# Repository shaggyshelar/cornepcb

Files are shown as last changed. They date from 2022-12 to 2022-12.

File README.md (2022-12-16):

# samoklava

## An autogenerated split 36 key keyboard

## Disclaimer

This is an early experimental prototype. Please do not rely on the autogenerated files and double check them manually
before sending them off to a PCB fab. The author and other random strangers on the internet have been able to produce
working keyboard prototypes from this repo; this does not mean that everything will work every time.

The author(s) waive(s) responsibility for any damage or regulatory violations caused by using this software (see
license). Please consult your local regulations around radio frequencies and what's allowed for DIY projects in your
country.

| left | right |
| --- | --- |
| left | right |

A 5x3 split keyboard with 3 thumb keys. There is nothing unique about the keyboard layout. It's inspired by Corne and
Kyria, and has the exact number of keys needed for the [Miryoku](https://github.com/manna-harbour/miryoku) layout.

The interesting thing about this keyboard is that it's a declarative design:

- Layout is declared using [Ergogen](https://github.com/mrzealot/ergogen/). See [this fork](https://github.com/soundmonster/ergogen).
- The build system uses Ergogen to translate YAML to a KiCad PCB and plate files for FR-4 fab or laser cutting
- uses [kicad-automation-scripts](https://github.com/productize/kicad-automation-scripts) and [FreeRouting](https://github.com/freerouting/freerouting) to **automatically route the traces on the PCB**
- uses [KiKit](https://github.com/yaqwsx/KiKit) to render PCB previews (see top of this file) and production-ready **Gerber files**

## Features

- Extra pins and a slider switch for battery for wireless Promicro clones (tested with nice!nano); the slider can be
  shorted with a jumper if `CONFIG_ZMK_SLEEP` is preferred.
- Wired operation with QMK should be possible but is not tested; TRRS footprints are included and routed. The pinout is
  identical with a five-column Corne sans the RGBLEDs.
- Reset switches are easily accessible. The footprints used are the same as on the Corne.

## How to

If you would like to modify this:

- fork it
- change `samoklava.yaml` to your liking
- push your changes; the `build.yml` GitHub Workflow will pick it up, autoroute and generate Gerbers, all in a zip file.
  See https://github.com/soundmonster/samoklava/actions
- or:
  - make sure to have Docker CLI and NodeJS installed
  - run `make setup clean all`
  - check the `output` folder for KiCad PCBs and Gerbers

See the [workflow](.github/workflows/build.yml) or the [Makefile](Makefile) for more details.
See [my ZMK config](https://github.com/soundmonster/samoklava-zmk-config) for a suggested keymap.

# Initialize

`make run init-footprint`

## Update following file and add below code

/node_modules/ergogen/src/footprints/index.js

`   bat: require('./bat'),
    b3u1000p: require('./b3u1000p'),
    pcm12: require('./pcm12'),
    promicro_pretty: require('./promicro_pretty')`

## Once files are generated then run following plugins

- freerouting
- Teardrops
- Round Tracks

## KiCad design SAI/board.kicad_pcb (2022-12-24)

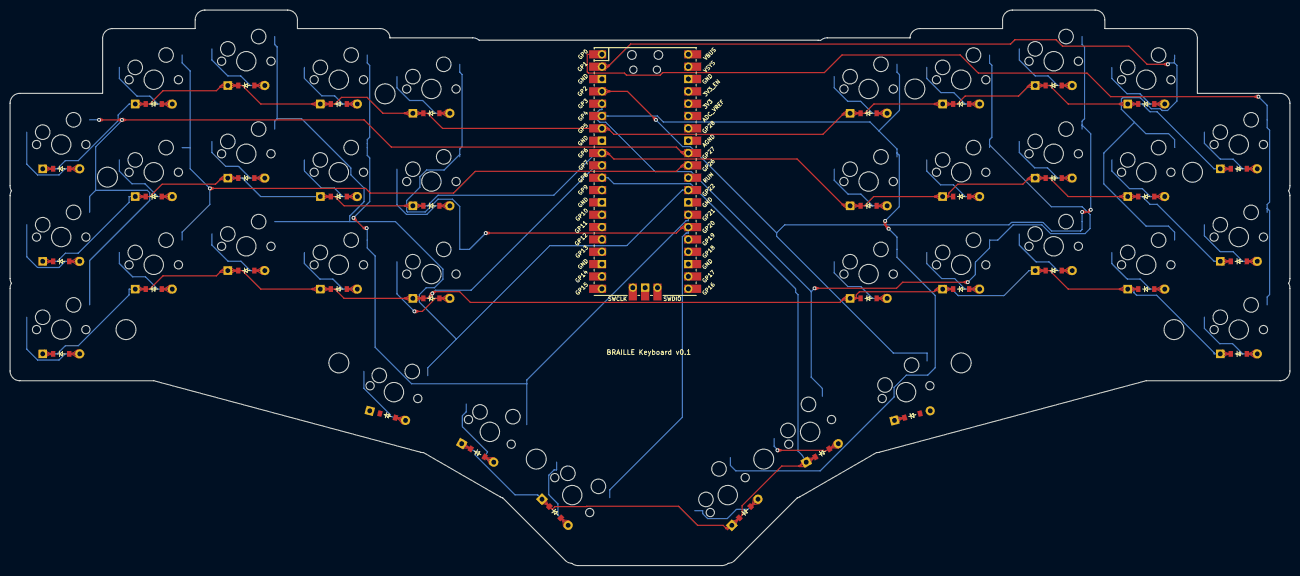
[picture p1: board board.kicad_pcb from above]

Board: 2 copper layers, 263.5 x 114.3 mm, 73 parts (0 on the bottom side), 50 nets.

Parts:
D1, D2, D3, D4, D5, D6, D7, D8, D9, D10, D11, D12, D13, D14, D15, D16, D17, D18, D19, D20, D21, D22, D23, D24, D25, D26, D27, D28, D29, D30, D31, D32, D33, D34, D35, D36: ComboDiode
MCU1: RPi_Pico_SMD_TH
S1, S2, S3, S4, S5, S6, S7, S8, S9, S10, S11, S12, S13, S14, S15, S16, S17, S18, S19, S20, S21, S22, S23, S24, S25, S26, S27, S28, S29, S30, S31, S32, S33, S34, S35, S36: MX

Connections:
C1: MCU1.32, S1.2, S2.2, S3.2
C2: MCU1.31, S4.2, S5.2, S6.2
C3: MCU1.29, S7.2, S8.2, S9.2, S16.2
C4: MCU1.27, S10.2, S11.2, S12.2, S17.2
C5: MCU1.26, S13.2, S14.2, S15.2, S18.2
C6: MCU1.6, S31.2, S32.2, S33.2, S36.2
C7: MCU1.5, S28.2, S29.2, S30.2, S35.2
C8: MCU1.4, S25.2, S26.2, S27.2, S34.2
C9: MCU1.2, S22.2, S23.2, S24.2
C10: MCU1.1, S19.2, S20.2, S21.2
R1: D3.1, D3.2, D6.1, D6.2, D9.1, D9.2, D12.1, D12.2, D15.1, D15.2, D21.1, D21.2, D24.1, D24.2, D27.1, D27.2, D30.1, D30.2, D33.1, D33.2, MCU1.7
R2: D2.1, D2.2, D5.1, D5.2, D8.1, D8.2, D11.1, D11.2, D14.1, D14.2, D20.1, D20.2, D23.1, D23.2, D26.1, D26.2, D29.1, D29.2, D32.1, D32.2, MCU1.9
R3: D1.1, D1.2, D4.1, D4.2, D7.1, D7.2, D10.1, D10.2, D13.1, D13.2, D19.1, D19.2, D22.1, D22.2, D25.1, D25.2, D28.1, D28.2, D31.1, D31.2, MCU1.10
R4: D16.1, D16.2, D17.1, D17.2, D18.1, D18.2, D34.1, D34.2, D35.1, D35.2, D36.1, D36.2, MCU1.11
far_thumb: D18.1, D18.2, S18.1
home_thumb: D17.1, D17.2, S17.1
index_bottom: D10.1, D10.2, S10.1
index_home: D11.1, D11.2, S11.1
index_top: D12.1, D12.2, S12.1
inner_bottom: D13.1, D13.2, S13.1
inner_home: D14.1, D14.2, S14.1
inner_top: D15.1, D15.2, S15.1
middle_bottom: D7.1, D7.2, S7.1
middle_home: D8.1, D8.2, S8.1
middle_top: D9.1, D9.2, S9.1
mirror_far_thumb: D36.1, D36.2, S36.1
mirror_home_thumb: D35.1, D35.2, S35.1
mirror_index_bottom: D28.1, D28.2, S28.1
mirror_index_home: D29.1, D29.2, S29.1
mirror_index_top: D30.1, D30.2, S30.1
mirror_inner_bottom: D31.1, D31.2, S31.1
mirror_inner_home: D32.1, D32.2, S32.1
mirror_inner_top: D33.1, D33.2, S33.1
mirror_middle_bottom: D25.1, D25.2, S25.1
mirror_middle_home: D26.1, D26.2, S26.1
mirror_middle_top: D27.1, D27.2, S27.1
mirror_near_thumb: D34.1, D34.2, S34.1
mirror_pinky_bottom: D19.1, D19.2, S19.1
mirror_pinky_home: D20.1, D20.2, S20.1
mirror_pinky_top: D21.1, D21.2, S21.1
mirror_ring_bottom: D22.1, D22.2, S22.1
mirror_ring_home: D23.1, D23.2, S23.1
mirror_ring_top: D24.1, D24.2, S24.1
near_thumb: D16.1, D16.2, S16.1
pinky_bottom: D1.1, D1.2, S1.1
pinky_home: D2.1, D2.2, S2.1
pinky_top: D3.1, D3.2, S3.1
ring_bottom: D4.1, D4.2, S4.1
ring_home: D5.1, D5.2, S5.1
ring_top: D6.1, D6.2, S6.1

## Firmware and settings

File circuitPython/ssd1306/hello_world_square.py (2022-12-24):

import os
import time
import busio
import board
import displayio
import terminalio
import adafruit_displayio_ssd1306
from adafruit_display_text import label

WIDTH = 128
HEIGHT = 64
CENTER_X = int(WIDTH/2)
CENTER_Y = int(HEIGHT/2)
BORDER = 5

displayio.release_displays()

# Initialize and lock the I2C bus.
i2c = busio.I2C(board.IO40, board.IO42)
while not i2c.try_lock():
    pass

print("$$$$$$$$$$$ Starting scan")
# Find the first I2C device available.
devices = i2c.scan()
while len(devices) < 1:
    devices = i2c.scan()
device = devices[0]
print('Found device with address: {}'.format(hex(device)))

i2c.unlock()


print("Initializing Library ..")
# Output: Found device with address: 0x3c

display_bus = displayio.I2CDisplay(i2c, device_address=0x3c)
display = adafruit_displayio_ssd1306.SSD1306(display_bus, width=128, height=64)


splash = displayio.Group()
display.show(splash)

color_bitmap = displayio.Bitmap(WIDTH, HEIGHT, 1)
color_palette = displayio.Palette(1)
color_palette[0] = 0xFFFFFF  # White
bg_sprite = displayio.TileGrid(
    color_bitmap, pixel_shader=color_palette, x=0, y=0)
splash.append(bg_sprite)
# Draw a smaller inner rectangle
inner_bitmap = displayio.Bitmap(WIDTH - BORDER * 2, HEIGHT - BORDER * 2, 1)
inner_palette = displayio.Palette(1)
inner_palette[0] = 0x000000  # Black
inner_sprite = displayio.TileGrid(
    inner_bitmap, pixel_shader=inner_palette, x=BORDER, y=BORDER
)
splash.append(inner_sprite)
# Draw a label
text = "Hello World!"
text_area = label.Label(
    terminalio.FONT, text=text, color=0xFFFFFF, x=28, y=HEIGHT // 2 - 1
)
splash.append(text_area)
while True:
    pass

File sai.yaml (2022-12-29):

units:
  kx: U
  ky: U
  px: 2
  py: 2
points:
  key:
    footprints:
      mx_hotswap:
        type: mx
        params:
          hotswap: true
          reverse: false
          keycaps: true
        nets:
          from: =colrow
          to: =column_net
      # mx:
      #   type: mx
      #   params:
      #     reverse: false
      #     keycaps: true
      #   nets:
      #     from: =colrow
      #     to: =column_net
      diode:
        type: diode
        nets:
          from: =colrow
          to: =row_net
        anchor:
          shift: [0, -5]
  zones:
    matrix:
      # anchor:
      #   rotate: 5
      key.padding: ky
      columns:
        pinky:
          stagger: 0 ky
          spread: kx
          key:
            bind: [0,9,0,0]
            column_net: C1
            mirror.column_net: C10
        ring:
          stagger: 0.7 ky
          spread: kx
          key:
            column_net: C2
            mirror.column_net: C9
        middle:
          stagger: 0.2 ky
          spread: kx
          key:
            column_net: C3
            mirror.column_net: C8
        index:
          stagger: -0.2 ky
          spread: kx
          key:
            column_net: C4
            mirror.column_net: C7
        inner:
          stagger: -0.1 ky
          spread: kx
          key:
            # bind: [0,40,20,0]
            column_net: C5
            mirror.column_net: C6
      rows:
        bottom:
          row_net: R3
        home:
          row_net: R2
        top:
          row_net: R1
    thumbfan:
      anchor:
        ref: matrix_inner_bottom
        shift: [-1.5 kx, -1 ky]
      columns:
        near:
          spread: kx
          rotate: -15
          origin: [-1 kx, -0.5 ky]
          key:
            column_net: C3
            mirror.column_net: C8
        home:
          spread: kx
          rotate: -15
          origin: [-0.5 kx, -0.5 ky]
          key:
            column_net: C4
            mirror.column_net: C7
        far:
          spread: kx
          rotate: -15
          origin: [-0.5 kx, -0.5 ky]
          key:
            column_net: C5
            mirror.column_net: C6
      rows:
        thumb:
          row_net: R4
          bind: [20,0,0,55]
  # rotate: -1
  mirror:
    ref: matrix_inner_home
    distance: 90
outlines:
  # glue:
  #   default:
  #     top:
  #       left:
  #         ref: matrix_inner_top
  #         shift: [,sy / 2]
  #       right:
  #         ref: mirror_matrix_inner_top
  #         shift: [,sy / 2]
  #     bottom:
  #       left:
  #         ref: matrix_inner_bottom
  #         shift: [,sy / -2]
  #       right:
  #         ref: mirror_matrix_inner_bottom
  #         shift: [,sy / -2]
  exports:
    # optout:
    #   main:
    #     type: keys
    #     side: both
    #     size: 20
    #     glue: false
    #     corner: px
    raw:
      - type: keys
        side: both
        size: [kx + px, ky + py]
        corner: px
    # thumbfan_glue:
    #   - type: polygon
    #     points:
    #       - ref: matrix_inner_bottom
    #         shift: [0.5 kx + 0.5px, -0.5 ky + 0.5 py]
    #       - ref: thumbfan_far_thumb
    #         shift: [0.5 kx - 0.5px, 0.5 ky + 0.5 py]
    #       - ref: thumbfan_far_thumb
    #         shift: [0.5 kx - 0.5px, -0.5 ky - 0.5 py]
    #       - ref: thumbfan_near_thumb
    #         shift: [-0.5 kx + 0.5 px, -0.5 ky - 0.5 py]
    #       - ref: matrix_pinky_bottom
    #         shift: [0.5 kx - 0.5 py, -0.5 ky - 0.5 py]
    #       - ref: matrix_pinky_home
    #       - ref: matrix_inner_home
    # patch_outer:
    #   - type: polygon
    #     points:
    #       - ref: matrix_ring_top
    #       - ref: matrix_ring_bottom
    #       - ref: matrix_pinky_bottom
    #         shift: [-0.5 (kx + px), 0]
    #       - ref: matrix_pinky_top
    #         shift: [-0.5 (kx + px), 0]
    # patch_inner:
    #   - type: polygon
    #     points:
    #       - ref: matrix_inner_top
    #         shift: [0.5 (kx + px), 0]
    #       - ref: matrix_inner_bottom
    #         shift: [0.5 (kx + px), 0]
    #       - ref: matrix_index_bottom
    #       - ref: matrix_index_top
    # controller_area:
    #   main:
    #     type: rectangle
    #     anchor:
    #       ref:
    #         - matrix_inner_top
    #       shift: [0.5 kx, -4.34 ky]
    #     size: [34, 90]
    #     #   shift: [0 kx, -4.05 ky]
    #     # size: [32, 76.5]
    #     corner: px
    pico_area:
      main:
        type: rectangle
        anchor:
          ref:
            - matrix_inner_top
          shift: [0.4 kx, -3.2 ky]
        size: [74, 71]
        corner: px
    pcb_area:
      main:
        type: rectangle
        anchor:
          ref:
            - matrix_inner_top
          shift: [-87, -5.15 ky]
        size: [265, 6 ky]
        corner: px
    bottom_area:
      main:
        type: rectangle
        anchor:
          ref:
            - matrix_inner_top
          shift: [1.48 kx, -5.15 ky]
        size: [33.64, 30]
        corner: px
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

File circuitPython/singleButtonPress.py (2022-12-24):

"""
Top Left side of button is connected to IO4
Bottom Right side of button is connected to GND

Buttons Tested: IO4,IO5,IO6,IO7,IO15,IO16,IO17,IO18,IO8,IO3,IO46,IO9,IO10,IO11,IO12,IO13,IO14
"""
import time
import board
from digitalio import DigitalInOut, Direction, Pull

btn = DigitalInOut(board.IO4)
btn.direction = Direction.INPUT
btn.pull = Pull.UP

while True:
    if not btn.value:
        print("BTN is down")
    else:
        # print("BTN is up")
        pass

    time.sleep(1)  # sleep for debounce

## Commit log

2022-12-16 Added copy script when boards are generated
    [board.kicad_pcb]
2022-12-16 Code cleanup
    [board.kicad_pcb]
2022-12-16 Add footprint config for b3u100p component
    [board.kicad_pcb]
2022-12-16 Add footprint config for bat, pcm12, promicro_pretty component
2022-12-17 Updated simple vai in SAI.kicad_pcb for initial PCB with only via
    [SAI.kicad_pcb]
2022-12-17 Added only PiPico footprint
    [SAI.kicad_pcb]
2022-12-17 Initial config of pi-pico footprint
2022-12-17 Added missing footprint config for pi_pico
2022-12-17 Completed pi pico footprint config
2022-12-20 Added glue example
2022-12-21 Added glue config
2022-12-21 Added pico area
2022-12-21 Added mirror screw holes
2022-12-21 Updated mounting holes
2022-12-21 Added updateIndex.js file to display content of footprint/index.js
2022-12-22 Updated PI Pico schematics and footprint to map unconnected pins
    [SAI.kicad_pcb, SAI.kicad_sch]
2022-12-22 Added edge cuts to Pico and now no warning or errors in DRC
    [SAI.kicad_pcb]
2022-12-22 Added separate files for Pico kicad configs
    [PICO.kicad_pcb, PICO.kicad_sch]
2022-12-22 Fixed screw holes issue
    [sai.yaml]
2022-12-24 Working PCB with 6 DRC warnings
    [board.kicad_pcb]
2022-12-24 Added I2C scan, ssd1306 sample
2022-12-24 I2C square bitmap example
2022-12-25 Added ESP32-S3-Devkit footprint
    [ESP32-S3-DevKit.kicad_pcb]
2022-12-25 Initial config of esp32s3_devkit
2022-12-25 Added row and column config for esp32
2022-12-25 Added square pcb area
2022-12-25 Added i2c
